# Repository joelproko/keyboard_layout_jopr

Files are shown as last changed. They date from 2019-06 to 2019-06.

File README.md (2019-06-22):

# keyboard_layout_jopr
This is my first attempt at a custom keyboard. It's inspired, among others, by https://github.com/itractus/KeyBored  
The firmware is located at https://github.com/joelproko/qmk_firmware/tree/jopr

This is a layout of what the microcontroller will probably send for which key:  

"default":  
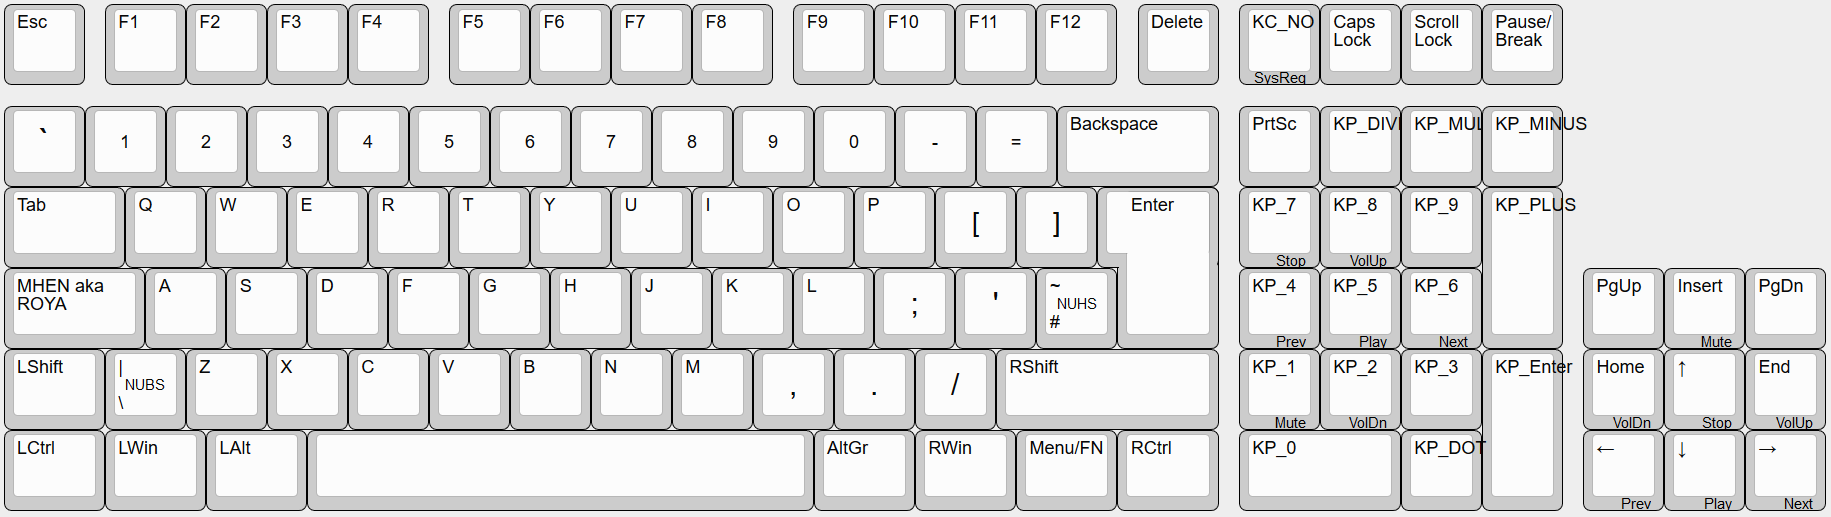
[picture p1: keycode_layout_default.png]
  
[Keyboard Layout Editor link](http://www.keyboard-layout-editor.com/#/gists/82594aeadc8321c39f5dd5e3733b16e5)

"modded-white": (based on https://github.com/mw8/white_keyboard_layout)  
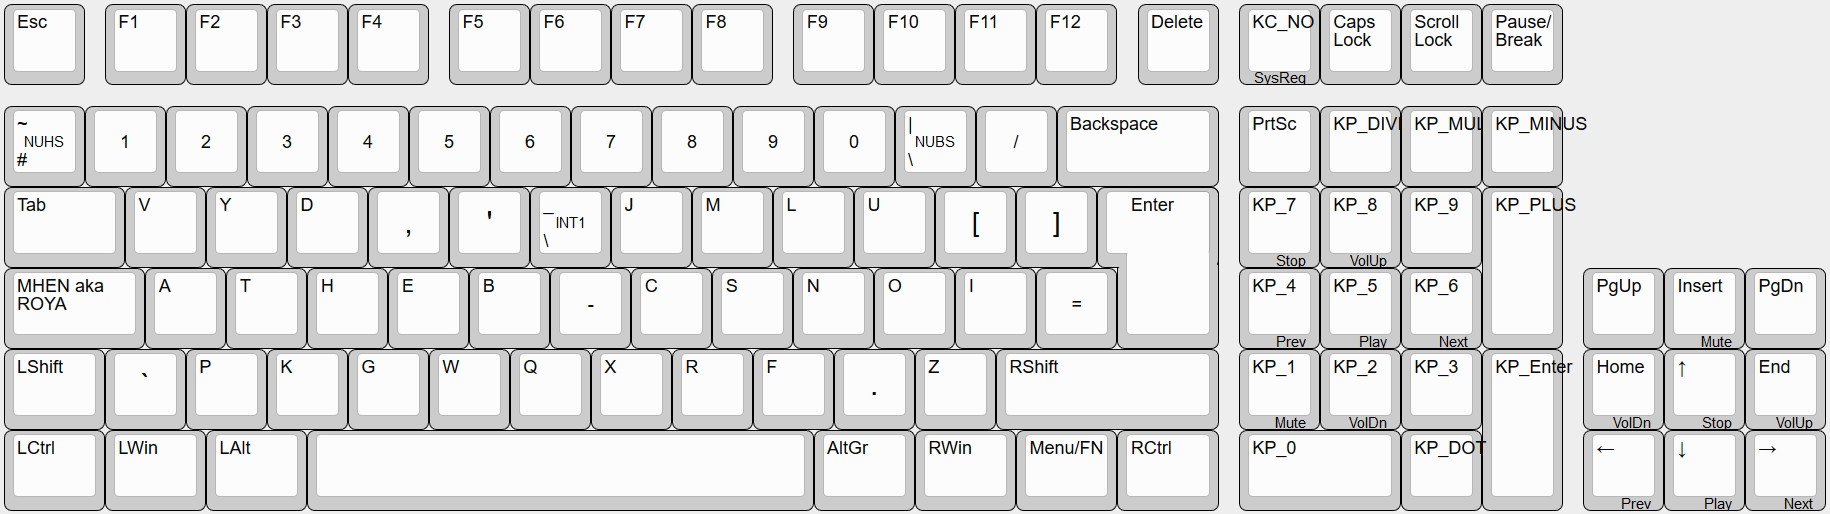
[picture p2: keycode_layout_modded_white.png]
  
[Keyboard Layout Editor link](http://www.keyboard-layout-editor.com/#/gists/e355f587c1d4540c1ec2808fc14671c6)

This a keycap design for the latter:  
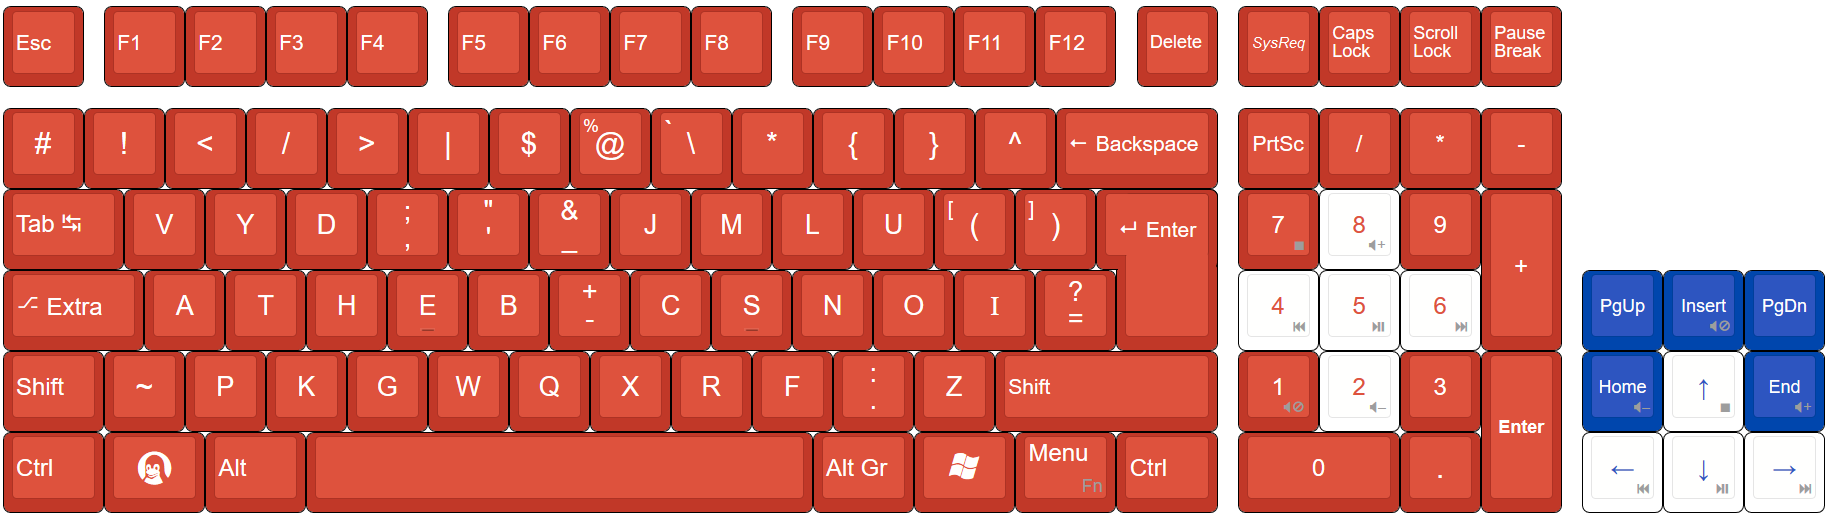
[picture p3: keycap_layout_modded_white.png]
  
[Keyboard Layout Editor link](http://www.keyboard-layout-editor.com/#/gists/73444aee1e5caa922be72c5b2b2db0ba)

There's a PDF of the schematic
here
and a PDF of the PCB
here (and [a version with separate pages for each layer](https://github.com/joelproko/keyboard_layout_jopr/raw/master/keyboard_layout_jopr.kicad_pcb.page_per_layer.pdf))

2019-06-22:  
So far, the PCB and the keycaps have arrived. I made a low quality photo on my phone.  
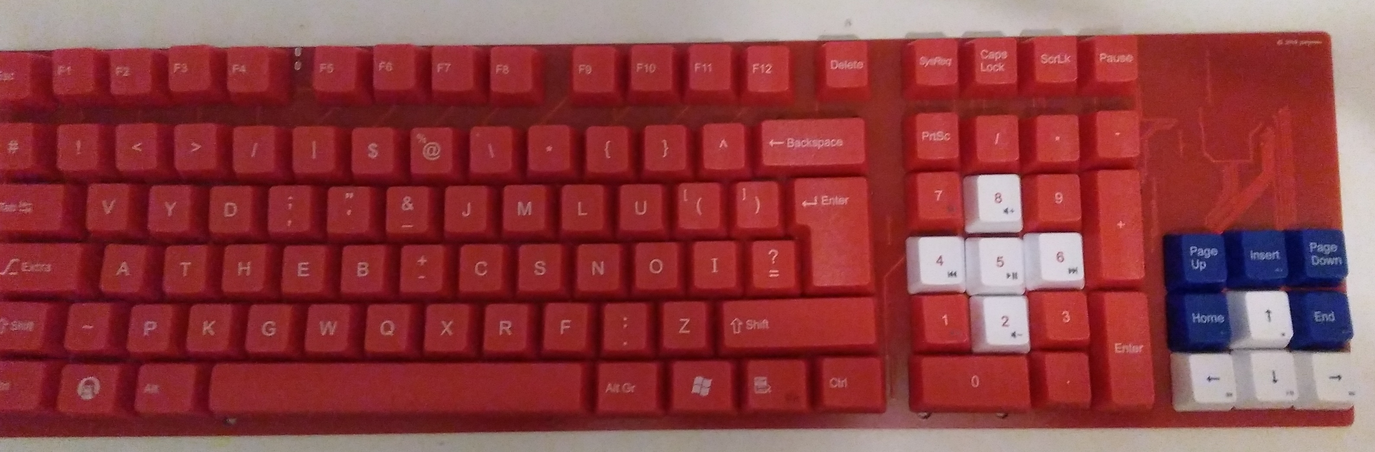
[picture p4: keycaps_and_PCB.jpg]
bad photograph of keycaps on top of PCB


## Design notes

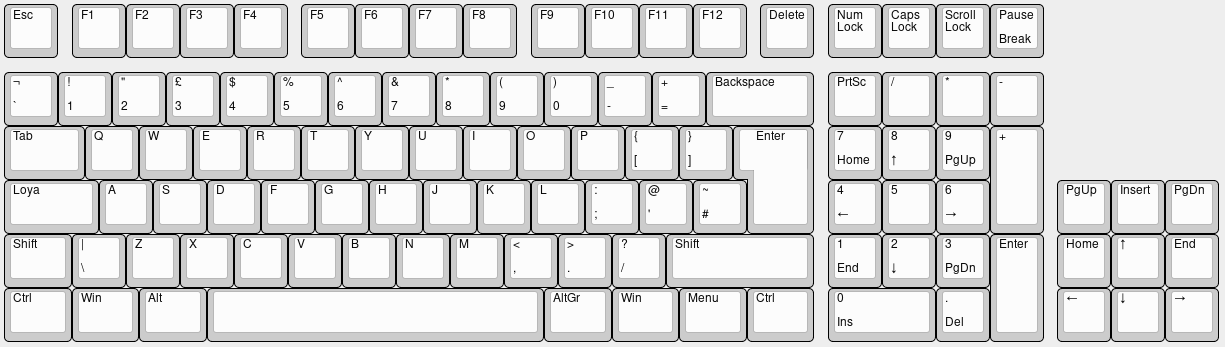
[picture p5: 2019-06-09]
keycode_layout.png

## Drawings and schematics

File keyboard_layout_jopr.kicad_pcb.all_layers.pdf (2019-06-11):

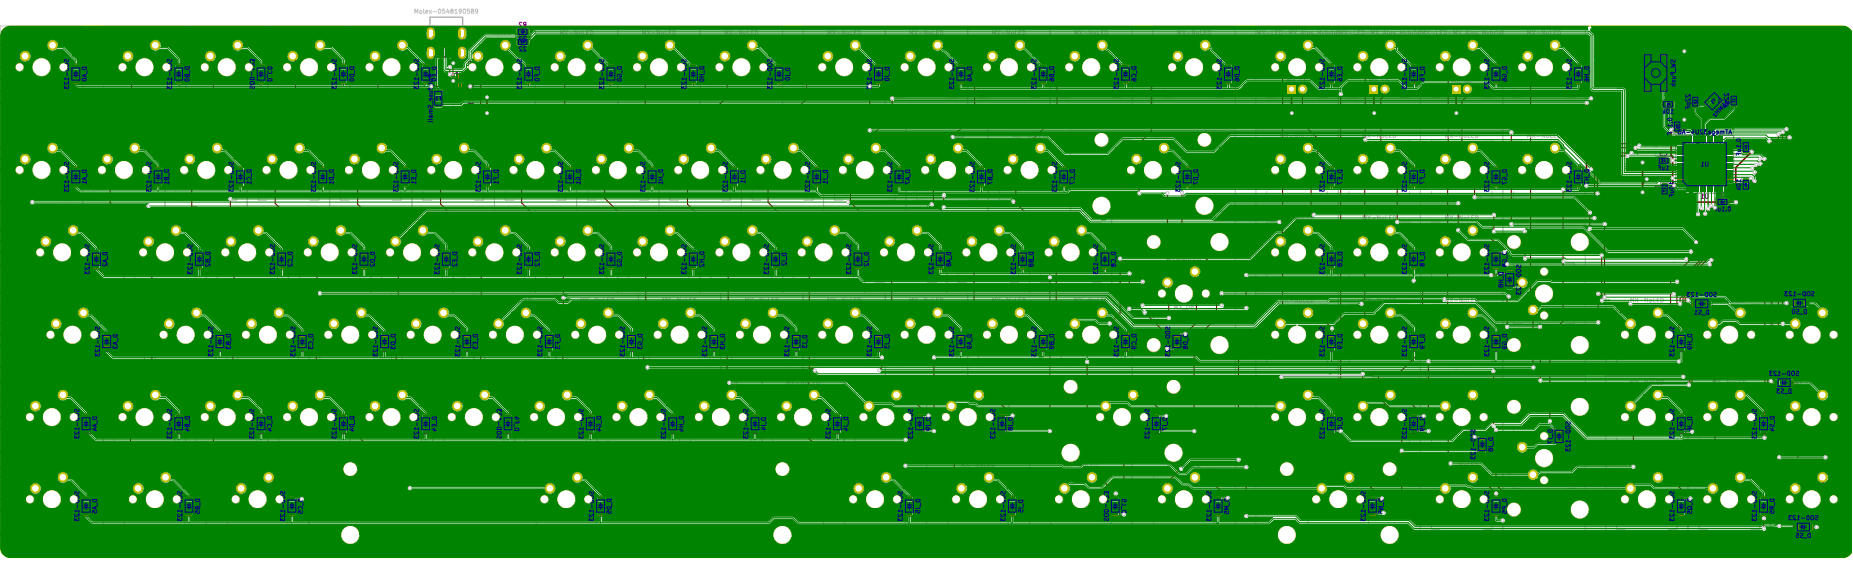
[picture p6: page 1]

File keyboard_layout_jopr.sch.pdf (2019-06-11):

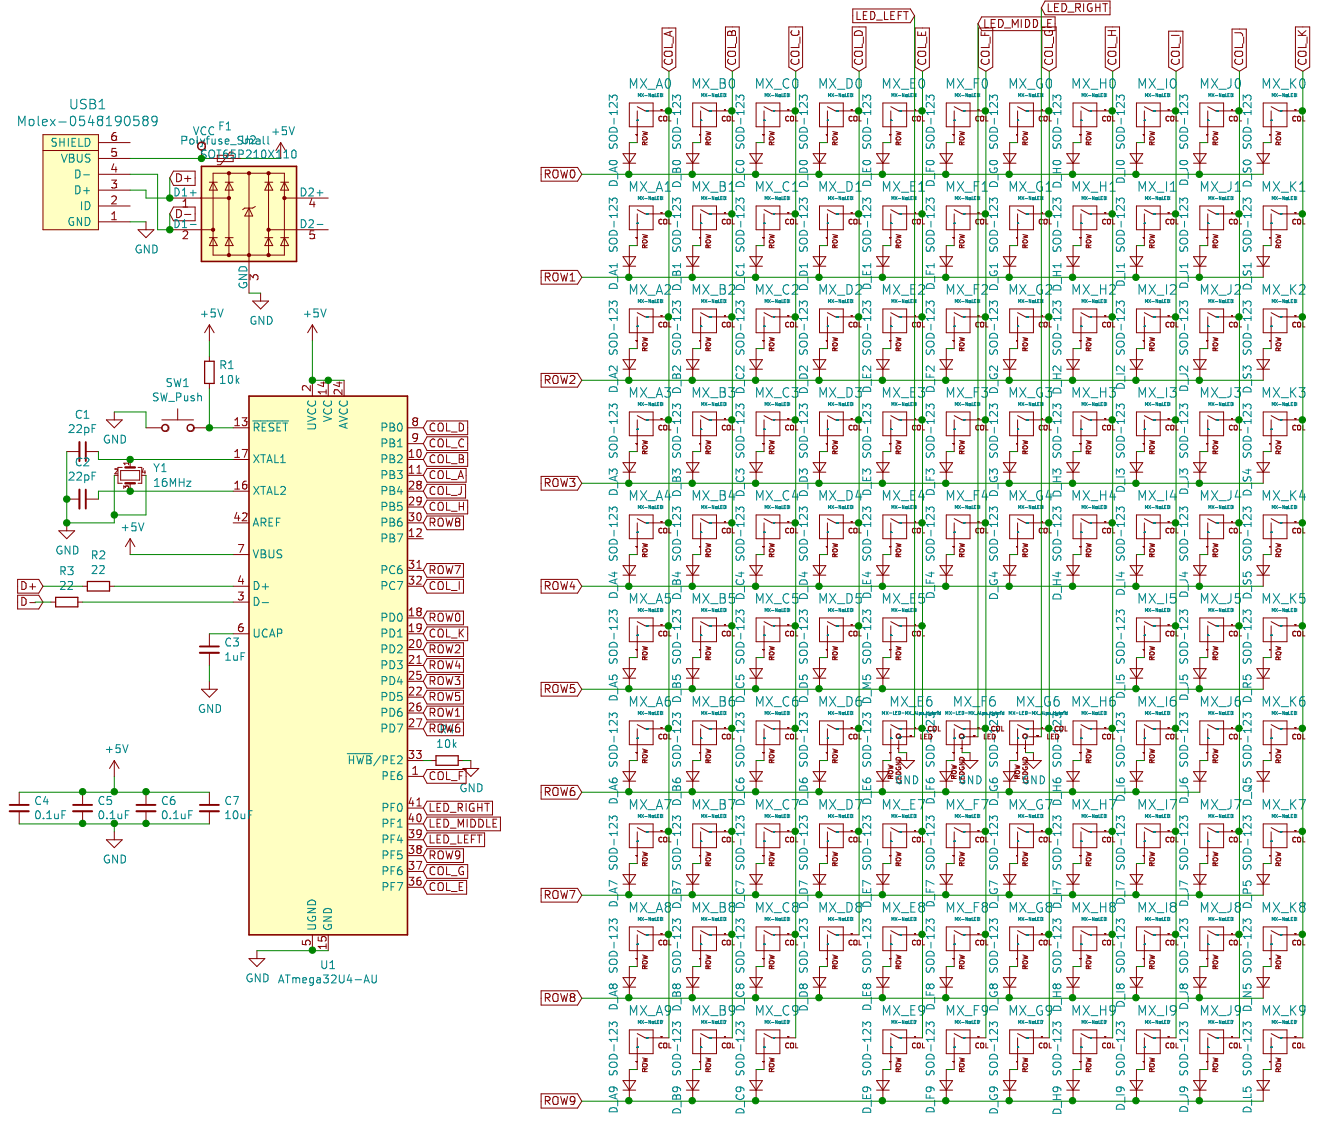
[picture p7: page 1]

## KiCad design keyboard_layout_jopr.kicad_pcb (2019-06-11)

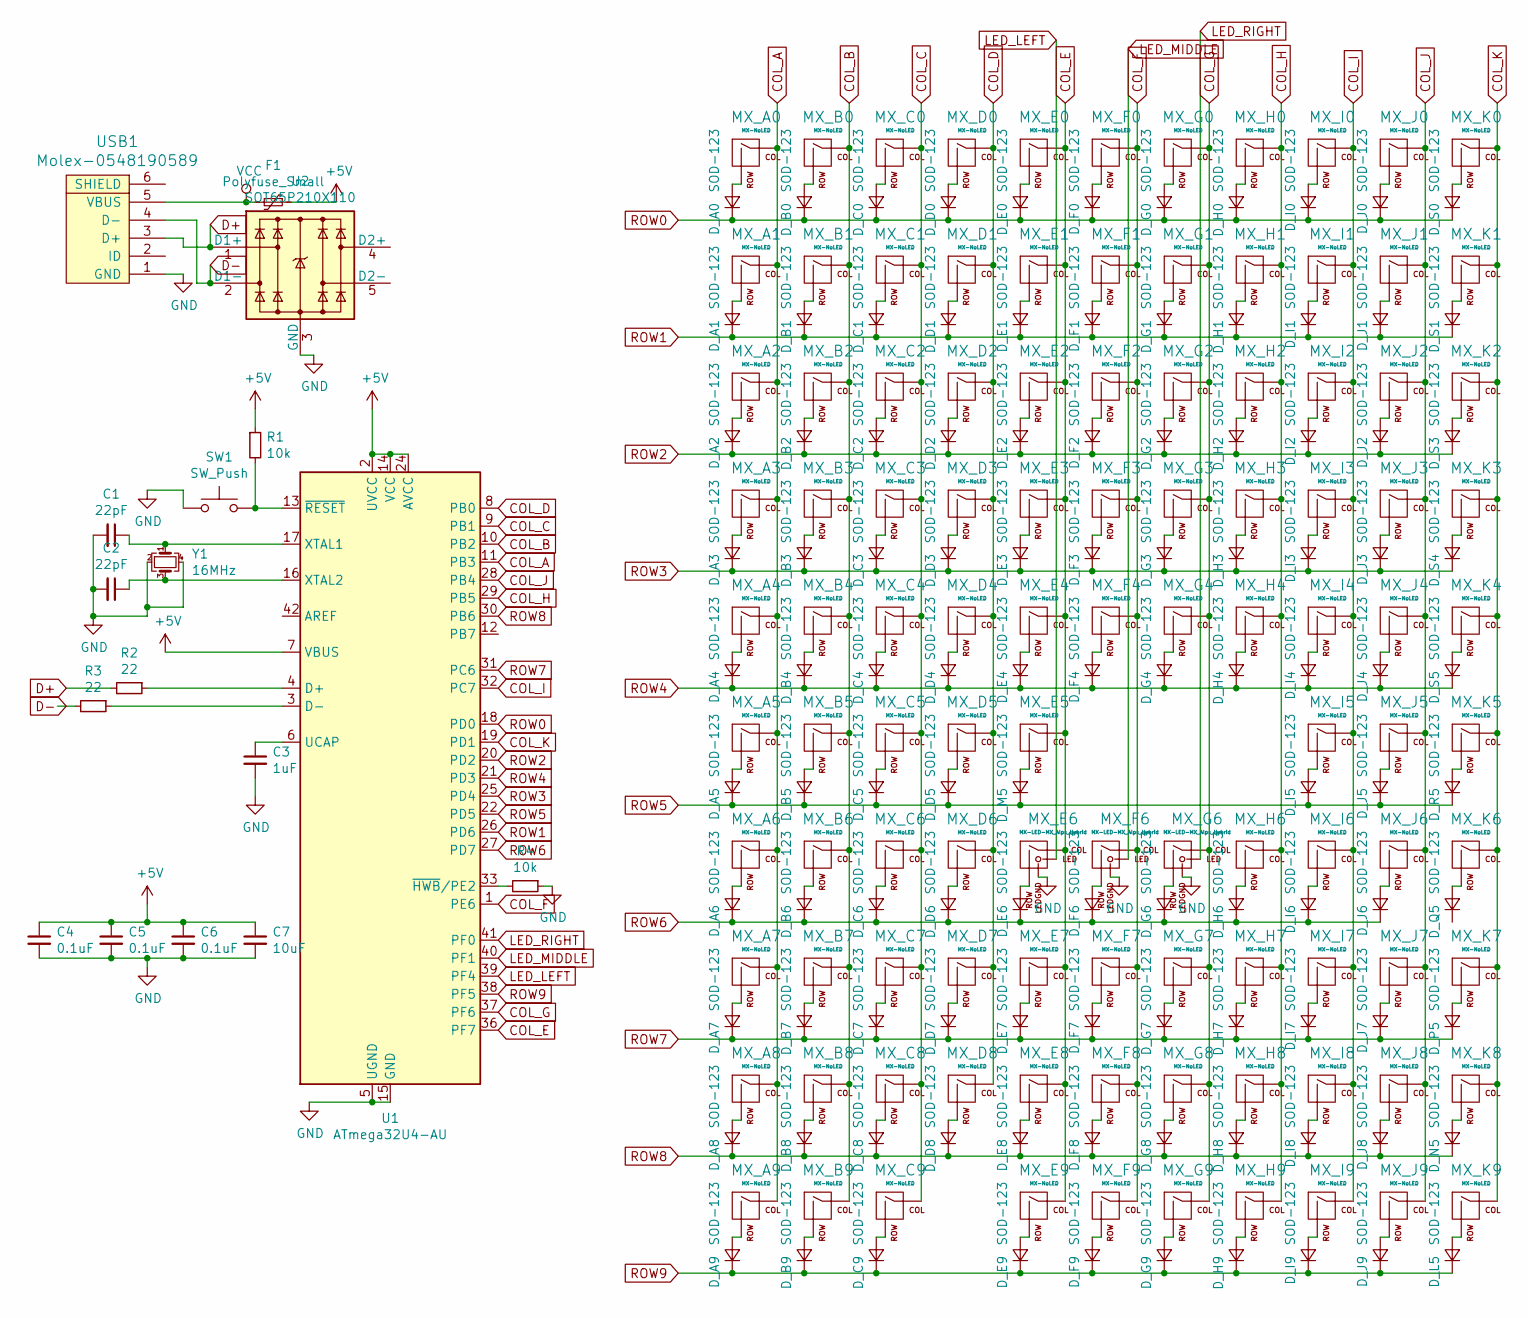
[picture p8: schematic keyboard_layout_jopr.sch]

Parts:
C1, C2: 22pF; C_0805_2012Metric
C3: 1uF; C_0805_2012Metric
C4, C5, C6: 0.1uF; C_0805_2012Metric
C7: 10uF; C_0805_2012Metric
D_A0, D_A1, D_A2, D_A3, D_A4, D_A5, D_A6, D_A7, D_A8, D_A9: SOD-123; D_SOD-123
D_B0, D_B1, D_B2, D_B3, D_B4, D_B5, D_B6, D_B7, D_B8, D_B9: SOD-123; D_SOD-123
D_C0, D_C1, D_C2, D_C3, D_C4, D_C5, D_C6, D_C7, D_C8, D_C9: SOD-123; D_SOD-123
D_D0, D_D1, D_D2, D_D3, D_D4, D_D5, D_D6, D_D7, D_D8: SOD-123; D_SOD-123
D_E0, D_E1, D_E2, D_E3, D_E4, D_E6, D_E7, D_E8, D_E9: SOD-123; D_SOD-123
D_F0, D_F1, D_F2, D_F3, D_F4, D_F6, D_F7, D_F8, D_F9: SOD-123; D_SOD-123
D_G0, D_G1, D_G2, D_G3, D_G4, D_G6, D_G7, D_G8, D_G9: SOD-123; D_SOD-123
D_H0, D_H1, D_H2, D_H3, D_H4, D_H6, D_H7, D_H8, D_H9: SOD-123; D_SOD-123
D_I0, D_I1, D_I2, D_I3, D_I4, D_I5, D_I6, D_I7, D_I8, D_I9: SOD-123; D_SOD-123
D_J0, D_J1, D_J2, D_J3, D_J4, D_J5, D_J6, D_J7, D_J8, D_J9: SOD-123; D_SOD-123
D_L5: SOD-123; D_SOD-123
D_M5: SOD-123; D_SOD-123
D_N5: SOD-123; D_SOD-123
D_P5: SOD-123; D_SOD-123
D_Q5: SOD-123; D_SOD-123
D_R5: SOD-123; D_SOD-123
D_S0, D_S1, D_S3, D_S4, D_S5: SOD-123; D_SOD-123
F1: Polyfuse_Small; Fuse_1206_3216Metric
MX_A0, MX_A1, MX_A6, MX_A7, MX_A8, MX_A9: MX-NoLED; MXOnly-1U-NoLED
MX_A2: MX-NoLED; MXOnly-1.5U-NoLED
MX_A3: MX-NoLED; MXOnly-1.75U-NoLED
MX_A4, MX_A5: MX-NoLED; MXOnly-1.25U-NoLED
MX_B0, MX_B1, MX_B2, MX_B3, MX_B4, MX_B6, MX_B7, MX_B8, MX_B9: MX-NoLED; MXOnly-1U-NoLED
MX_B5: MX-NoLED; MXOnly-1.25U-NoLED
MX_C0, MX_C1, MX_C2, MX_C3, MX_C4, MX_C6, MX_C7, MX_C8, MX_C9: MX-NoLED; MXOnly-1U-NoLED
MX_C5: MX-NoLED; MXOnly-1.25U-NoLED
MX_D0, MX_D1, MX_D2, MX_D3, MX_D4, MX_D6: MX-NoLED; MXOnly-1U-NoLED
MX_D5: MX-NoLED; MXOnly-6.25U-NoLED
MX_D7: MX-NoLED; MXOnly-2U-NoLED
MX_D8: MX-NoLED; MXOnly-ISO-NoLED
MX_E0, MX_E1, MX_E2, MX_E3, MX_E4, MX_E7, MX_E8, MX_E9: MX-NoLED; MXOnly-1U-NoLED
MX_E5: MX-NoLED; MXOnly-1.25U-NoLED
MX_E6: MX-LED-MX_Alps_Hybrid; MXOnly-1U-FLIPPED
MX_F0, MX_F1, MX_F2, MX_F3, MX_F4, MX_F7, MX_F8, MX_F9: MX-NoLED; MXOnly-1U-NoLED
MX_F6: MX-LED-MX_Alps_Hybrid; MXOnly-1U-FLIPPED
MX_G0, MX_G1, MX_G2, MX_G3, MX_G4, MX_G7, MX_G8, MX_G9: MX-NoLED; MXOnly-1U-NoLED
MX_G6: MX-LED-MX_Alps_Hybrid; MXOnly-1U-FLIPPED
MX_H0, MX_H1, MX_H2, MX_H3, MX_H4, MX_H6, MX_H7, MX_H9: MX-NoLED; MXOnly-1U-NoLED
MX_H8: MX-NoLED; MXOnly-2U-NoLED
MX_I0, MX_I1, MX_I2, MX_I3, MX_I4, MX_I6, MX_I8, MX_I9: MX-NoLED; MXOnly-1U-NoLED
MX_I5: MX-NoLED; MXOnly-1.25U-NoLED
MX_I7: MX-NoLED; MXOnly-2.75U-NoLED
MX_J0, MX_J1, MX_J2, MX_J3, MX_J4, MX_J6, MX_J8, MX_J9: MX-NoLED; MXOnly-1U-NoLED
MX_J5: MX-NoLED; MXOnly-1.25U-NoLED
MX_J7: MX-NoLED; MXOnly-2U-NoLED
MX_K0, MX_K1, MX_K2, MX_K3, MX_K4, MX_K5, MX_K6, MX_K7: MX-NoLED; MXOnly-1U-NoLED
MX_K8: MX-NoLED; MXOnly-2U-NoLED
MX_K9: MX-NoLED; MXOnly-1.25U-NoLED
R1, R4: 10k; R_0805_2012Metric
R2, R3: 22; R_0805_2012Metric
SW1: SW_Push; SKQG-1155865
U1: ATmega32U4-AU; TQFP-44_10x10mm_P0.8mm
U2: SOT65P210X110; SOT65P210X110-6N
USB1: Molex-0548190589
Y1: 16MHz; Crystal_SMD_3225-4Pin_3.2x2.5mm

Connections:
+5V: C4.1, C5.1, C6.1, C7.1, F1.1, R1.1, U1.2 (UVCC), U1.7 (VBUS), U1.14 (VCC), U1.24 (AVCC), U1.34 (VCC), U1.44 (AVCC)
COL_A: MX_A0.1 (COL), MX_A1.1 (COL), MX_A2.1 (COL), MX_A3.1 (COL), MX_A4.1 (COL), MX_A5.1 (COL), MX_A6.1 (COL), MX_A7.1 (COL), MX_A8.1 (COL), MX_A9.1 (COL), U1.11 (PB3)
COL_B: MX_B0.1 (COL), MX_B1.1 (COL), MX_B2.1 (COL), MX_B3.1 (COL), MX_B4.1 (COL), MX_B5.1 (COL), MX_B6.1 (COL), MX_B7.1 (COL), MX_B8.1 (COL), MX_B9.1 (COL), U1.10 (PB2)
COL_C: MX_C0.1 (COL), MX_C1.1 (COL), MX_C2.1 (COL), MX_C3.1 (COL), MX_C4.1 (COL), MX_C5.1 (COL), MX_C6.1 (COL), MX_C7.1 (COL), MX_C8.1 (COL), MX_C9.1 (COL), U1.9 (PB1)
COL_D: MX_D0.1 (COL), MX_D1.1 (COL), MX_D2.1 (COL), MX_D3.1 (COL), MX_D4.1 (COL), MX_D5.1 (COL), MX_D6.1 (COL), MX_D7.1 (COL), MX_D8.1 (COL), U1.8 (PB0)
COL_E: MX_E0.1 (COL), MX_E1.1 (COL), MX_E2.1 (COL), MX_E3.1 (COL), MX_E4.1 (COL), MX_E5.1 (COL), MX_E6.1 (COL), MX_E7.1 (COL), MX_E8.1 (COL), MX_E9.1 (COL), U1.36 (PF7)
COL_F: MX_F0.1 (COL), MX_F1.1 (COL), MX_F2.1 (COL), MX_F3.1 (COL), MX_F4.1 (COL), MX_F6.1 (COL), MX_F7.1 (COL), MX_F8.1 (COL), MX_F9.1 (COL), U1.1 (PE6)
COL_G: MX_G0.1 (COL), MX_G1.1 (COL), MX_G2.1 (COL), MX_G3.1 (COL), MX_G4.1 (COL), MX_G6.1 (COL), MX_G7.1 (COL), MX_G8.1 (COL), MX_G9.1 (COL), U1.37 (PF6)
COL_H: MX_H0.1 (COL), MX_H1.1 (COL), MX_H2.1 (COL), MX_H3.1 (COL), MX_H4.1 (COL), MX_H6.1 (COL), MX_H7.1 (COL), MX_H8.1 (COL), MX_H9.1 (COL), U1.29 (PB5)
COL_I: MX_I0.1 (COL), MX_I1.1 (COL), MX_I2.1 (COL), MX_I3.1 (COL), MX_I4.1 (COL), MX_I5.1 (COL), MX_I6.1 (COL), MX_I7.1 (COL), MX_I8.1 (COL), MX_I9.1 (COL), U1.32 (PC7)
COL_J: MX_J0.1 (COL), MX_J1.1 (COL), MX_J2.1 (COL), MX_J3.1 (COL), MX_J4.1 (COL), MX_J5.1 (COL), MX_J6.1 (COL), MX_J7.1 (COL), MX_J8.1 (COL), MX_J9.1 (COL), U1.28 (PB4)
COL_K: MX_K0.1 (COL), MX_K1.1 (COL), MX_K2.1 (COL), MX_K3.1 (COL), MX_K4.1 (COL), MX_K5.1 (COL), MX_K6.1 (COL), MX_K7.1 (COL), MX_K8.1 (COL), MX_K9.1 (COL), U1.19 (PD1)
D+: R2.2, U2.1 (D1+), USB1.3 (D+)
D-: R3.2, U2.2 (D1-), USB1.4 (D-)
GND: C1.2, C2.2, C3.2, C4.2, C5.2, C6.2, C7.2, MX_E6.4 (LEDGND), MX_F6.4 (LEDGND), MX_G6.4 (LEDGND), R4.1, SW1.1, U1.5 (UGND), U1.15 (GND), U1.23 (GND), U1.35 (GND), U1.43 (GND), U2.3 (GND), U2.8 (GND), USB1.1 (GND), Y1.2, Y1.4
LED_LEFT: MX_E6.3 (LED), U1.39 (PF4)
LED_MIDDLE: MX_F6.3 (LED), U1.40 (PF1)
LED_RIGHT: MX_G6.3 (LED), U1.41 (PF0)
unnamed: C1.1, U1.17 (XTAL1), Y1.1
unnamed: C2.1, U1.16 (XTAL2), Y1.3
unnamed: C3.1, U1.6 (UCAP)
unnamed: D_A0.2 (A), MX_A0.2 (ROW)
unnamed: D_A1.2 (A), MX_A1.2 (ROW)
unnamed: D_A2.2 (A), MX_A2.2 (ROW)
unnamed: D_A3.2 (A), MX_A3.2 (ROW)
unnamed: D_A4.2 (A), MX_A4.2 (ROW)
unnamed: D_A5.2 (A), MX_A5.2 (ROW)
unnamed: D_A6.2 (A), MX_A6.2 (ROW)
unnamed: D_A7.2 (A), MX_A7.2 (ROW)
unnamed: D_A8.2 (A), MX_A8.2 (ROW)
unnamed: D_A9.2 (A), MX_A9.2 (ROW)
unnamed: D_B0.2 (A), MX_B0.2 (ROW)
unnamed: D_B1.2 (A), MX_B1.2 (ROW)
unnamed: D_B2.2 (A), MX_B2.2 (ROW)
unnamed: D_B3.2 (A), MX_B3.2 (ROW)
unnamed: D_B4.2 (A), MX_B4.2 (ROW)
unnamed: D_B5.2 (A), MX_B5.2 (ROW)
unnamed: D_B6.2 (A), MX_B6.2 (ROW)
unnamed: D_B7.2 (A), MX_B7.2 (ROW)
unnamed: D_B8.2 (A), MX_B8.2 (ROW)
unnamed: D_B9.2 (A), MX_B9.2 (ROW)
unnamed: D_C0.2 (A), MX_C0.2 (ROW)
unnamed: D_C1.2 (A), MX_C1.2 (ROW)
unnamed: D_C2.2 (A), MX_C2.2 (ROW)
unnamed: D_C3.2 (A), MX_C3.2 (ROW)
unnamed: D_C4.2 (A), MX_C4.2 (ROW)
unnamed: D_C5.2 (A), MX_C5.2 (ROW)
unnamed: D_C6.2 (A), MX_C6.2 (ROW)
unnamed: D_C7.2 (A), MX_C7.2 (ROW)
unnamed: D_C8.2 (A), MX_C8.2 (ROW)
unnamed: D_C9.2 (A), MX_C9.2 (ROW)
unnamed: D_D0.2 (A), MX_D0.2 (ROW)
unnamed: D_D1.2 (A), MX_D1.2 (ROW)
unnamed: D_D2.2 (A), MX_D2.2 (ROW)
unnamed: D_D3.2 (A), MX_D3.2 (ROW)
unnamed: D_D4.2 (A), MX_D4.2 (ROW)
unnamed: D_D5.2 (A), MX_D5.2 (ROW)
unnamed: D_D6.2 (A), MX_D6.2 (ROW)
unnamed: D_D7.2 (A), MX_D7.2 (ROW)
unnamed: D_D8.2 (A), MX_D8.2 (ROW)
unnamed: D_E0.2 (A), MX_E0.2 (ROW)
unnamed: D_E1.2 (A), MX_E1.2 (ROW)
unnamed: D_E2.2 (A), MX_E2.2 (ROW)
unnamed: D_E3.2 (A), MX_E3.2 (ROW)
unnamed: D_E4.2 (A), MX_E4.2 (ROW)
unnamed: D_E6.2 (A), MX_E6.2 (ROW)
unnamed: D_E7.2 (A), MX_E7.2 (ROW)
unnamed: D_E8.2 (A), MX_E8.2 (ROW)
unnamed: D_E9.2 (A), MX_E9.2 (ROW)
unnamed: D_F0.2 (A), MX_F0.2 (ROW)
unnamed: D_F1.2 (A), MX_F1.2 (ROW)
unnamed: D_F2.2 (A), MX_F2.2 (ROW)
unnamed: D_F3.2 (A), MX_F3.2 (ROW)
unnamed: D_F4.2 (A), MX_F4.2 (ROW)
unnamed: D_F6.2 (A), MX_F6.2 (ROW)
unnamed: D_F7.2 (A), MX_F7.2 (ROW)
unnamed: D_F8.2 (A), MX_F8.2 (ROW)
unnamed: D_F9.2 (A), MX_F9.2 (ROW)
unnamed: D_G0.2 (A), MX_G0.2 (ROW)
unnamed: D_G1.2 (A), MX_G1.2 (ROW)
unnamed: D_G2.2 (A), MX_G2.2 (ROW)
unnamed: D_G3.2 (A), MX_G3.2 (ROW)
unnamed: D_G4.2 (A), MX_G4.2 (ROW)
unnamed: D_G6.2 (A), MX_G6.2 (ROW)
unnamed: D_G7.2 (A), MX_G7.2 (ROW)
unnamed: D_G8.2 (A), MX_G8.2 (ROW)
unnamed: D_G9.2 (A), MX_G9.2 (ROW)
unnamed: D_H0.2 (A), MX_H0.2 (ROW)
unnamed: D_H1.2 (A), MX_H1.2 (ROW)
unnamed: D_H2.2 (A), MX_H2.2 (ROW)
unnamed: D_H3.2 (A), MX_H3.2 (ROW)
unnamed: D_H4.2 (A), MX_H4.2 (ROW)
unnamed: D_H6.2 (A), MX_H6.2 (ROW)
unnamed: D_H7.2 (A), MX_H7.2 (ROW)
unnamed: D_H8.2 (A), MX_H8.2 (ROW)
unnamed: D_H9.2 (A), MX_H9.2 (ROW)
unnamed: D_I0.2 (A), MX_I0.2 (ROW)
unnamed: D_I1.2 (A), MX_I1.2 (ROW)
unnamed: D_I2.2 (A), MX_I2.2 (ROW)
unnamed: D_I3.2 (A), MX_I3.2 (ROW)
unnamed: D_I4.2 (A), MX_I4.2 (ROW)
unnamed: D_I5.2 (A), MX_I5.2 (ROW)
unnamed: D_I6.2 (A), MX_I6.2 (ROW)
unnamed: D_I7.2 (A), MX_I7.2 (ROW)
unnamed: D_I8.2 (A), MX_I8.2 (ROW)
unnamed: D_I9.2 (A), MX_I9.2 (ROW)
unnamed: D_J0.2 (A), MX_J0.2 (ROW)
unnamed: D_J1.2 (A), MX_J1.2 (ROW)
unnamed: D_J2.2 (A), MX_J2.2 (ROW)
unnamed: D_J3.2 (A), MX_J3.2 (ROW)
unnamed: D_J4.2 (A), MX_J4.2 (ROW)
unnamed: D_J5.2 (A), MX_J5.2 (ROW)
unnamed: D_J6.2 (A), MX_J6.2 (ROW)
unnamed: D_J7.2 (A), MX_J7.2 (ROW)
unnamed: D_J8.2 (A), MX_J8.2 (ROW)
unnamed: D_J9.2 (A), MX_J9.2 (ROW)
unnamed: D_L5.2 (A), MX_K9.2 (ROW)
unnamed: D_M5.2 (A), MX_E5.2 (ROW)
unnamed: D_N5.2 (A), MX_K8.2 (ROW)
unnamed: D_P5.2 (A), MX_K7.2 (ROW)
unnamed: D_Q5.2 (A), MX_K6.2 (ROW)
unnamed: D_R5.2 (A), MX_K5.2 (ROW)
unnamed: D_S0.2 (A), MX_K0.2 (ROW)
unnamed: D_S1.2 (A), MX_K1.2 (ROW)
unnamed: D_S3.2 (A), MX_K2.2 (ROW)
unnamed: D_S4.2 (A), MX_K3.2 (ROW)
unnamed: D_S5.2 (A), MX_K4.2 (ROW)
unnamed: R1.2, SW1.2, U1.13 (~RESET)
unnamed: R2.1, U1.4 (D+)
unnamed: R3.1, U1.3 (D-)
unnamed: R4.2, U1.33 (~HWB~/PE2)
ROW0: D_A0.1 (K), D_B0.1 (K), D_C0.1 (K), D_D0.1 (K), D_E0.1 (K), D_F0.1 (K), D_G0.1 (K), D_H0.1 (K), D_I0.1 (K), D_J0.1 (K), D_S0.1 (K), U1.18 (PD0)
ROW1: D_A1.1 (K), D_B1.1 (K), D_C1.1 (K), D_D1.1 (K), D_E1.1 (K), D_F1.1 (K), D_G1.1 (K), D_H1.1 (K), D_I1.1 (K), D_J1.1 (K), D_S1.1 (K), U1.26 (PD6)
ROW2: D_A2.1 (K), D_B2.1 (K), D_C2.1 (K), D_D2.1 (K), D_E2.1 (K), D_F2.1 (K), D_G2.1 (K), D_H2.1 (K), D_I2.1 (K), D_J2.1 (K), D_S3.1 (K), U1.20 (PD2)
ROW3: D_A3.1 (K), D_B3.1 (K), D_C3.1 (K), D_D3.1 (K), D_E3.1 (K), D_F3.1 (K), D_G3.1 (K), D_H3.1 (K), D_I3.1 (K), D_J3.1 (K), D_S4.1 (K), U1.25 (PD4)
ROW4: D_A4.1 (K), D_B4.1 (K), D_C4.1 (K), D_D4.1 (K), D_E4.1 (K), D_F4.1 (K), D_G4.1 (K), D_H4.1 (K), D_I4.1 (K), D_J4.1 (K), D_S5.1 (K), U1.21 (PD3)
ROW5: D_A5.1 (K), D_B5.1 (K), D_C5.1 (K), D_D5.1 (K), D_I5.1 (K), D_J5.1 (K), D_M5.1 (K), D_R5.1 (K), U1.22 (PD5)
ROW6: D_A6.1 (K), D_B6.1 (K), D_C6.1 (K), D_D6.1 (K), D_E6.1 (K), D_F6.1 (K), D_G6.1 (K), D_H6.1 (K), D_I6.1 (K), D_J6.1 (K), U1.27 (PD7)
ROW7: D_A7.1 (K), D_B7.1 (K), D_C7.1 (K), D_D7.1 (K), D_E7.1 (K), D_F7.1 (K), D_G7.1 (K), D_H7.1 (K), D_I7.1 (K), D_J7.1 (K), D_P5.1 (K), U1.31 (PC6)
ROW8: D_A8.1 (K), D_B8.1 (K), D_C8.1 (K), D_D8.1 (K), D_E8.1 (K), D_F8.1 (K), D_G8.1 (K), D_H8.1 (K), D_I8.1 (K), D_J8.1 (K), D_N5.1 (K), U1.30 (PB6)
ROW9: D_A9.1 (K), D_B9.1 (K), D_C9.1 (K), D_E9.1 (K), D_F9.1 (K), D_G9.1 (K), D_H9.1 (K), D_I9.1 (K), D_J9.1 (K), D_L5.1 (K), U1.38 (PF5)
VCC: F1.2, USB1.5 (VBUS)

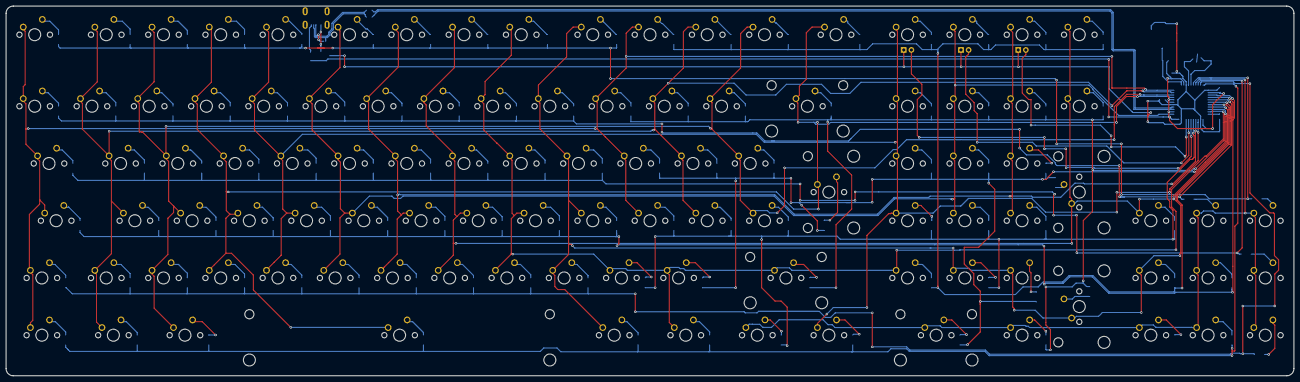
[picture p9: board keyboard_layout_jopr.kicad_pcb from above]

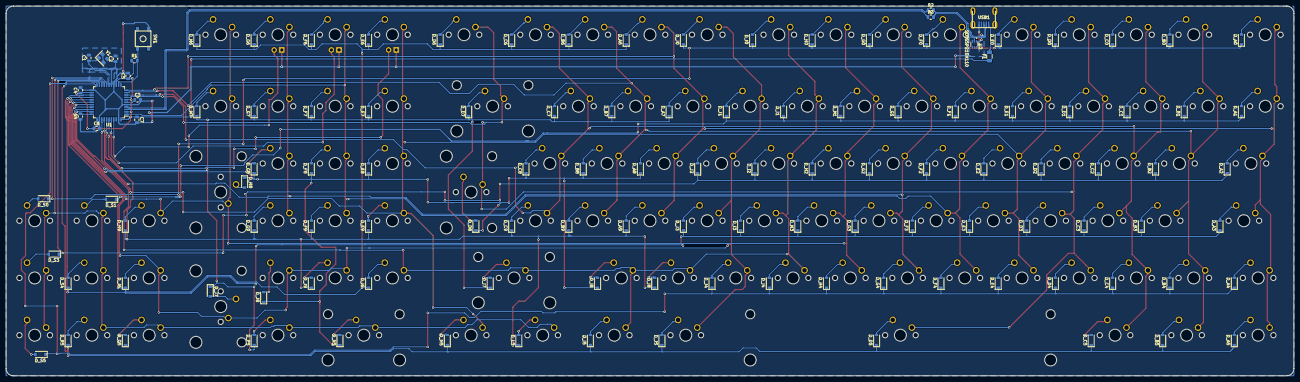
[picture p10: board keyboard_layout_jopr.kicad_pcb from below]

Board: 2 copper layers, 428.6 x 123.0 mm, 229 parts (123 on the bottom side), 142 nets.

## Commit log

2019-06-07 kicad init
    [keyboard_layout_jopr.kicad_pcb, keyboard_layout_jopr.sch]
2019-06-08 maybe done with the kicad part?
2019-06-08 Inter-key tracks and USB Data tracks only
    [keyboard_layout_jopr.kicad_pcb, keyboard_layout_jopr.sch, keyboard_layout_jopr_v01.kicad_pcb]
2019-06-08 maybe better tracks
    [keyboard_layout_jopr.kicad_pcb, keyboard_layout_jopr.sch, keyboard_layout_jopr_v01.kicad_pcb]
2019-06-09 replaced MX_Hybrid with MX_Only footprints
    [keyboard_layout_jopr.kicad_pcb]
2019-06-09 PDF-Versions of current state of schematic and pcb
2019-06-10 added ESD-protection
    [keyboard_layout_jopr.kicad_pcb, keyboard_layout_jopr.sch]
2019-06-11 squared matrix, updated and renamed PDFs
    [keyboard_layout_jopr.kicad_pcb, keyboard_layout_jopr.sch]
2019-06-11 generated Gerber files
    [keyboard_layout_jopr-B_Cu.gbr, keyboard_layout_jopr-B_Mask.gbr, keyboard_layout_jopr-B_SilkS.gbr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]
2019-06-11 moved lower edge down
    [keyboard_layout_jopr-B_Cu.gbr, keyboard_layout_jopr-B_Mask.gbr, keyboard_layout_jopr-B_SilkS.gbr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]
2019-06-11 moved lower PCB edge down
    [keyboard_layout_jopr-B_Cu.gbr, keyboard_layout_jopr-B_Mask.gbr, keyboard_layout_jopr-B_SilkS.gbr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]
2019-06-11 added LEDs for Lock keys
    [keyboard_layout_jopr-B_Cu.gbr, keyboard_layout_jopr-B_Mask.gbr, keyboard_layout_jopr-B_SilkS.gbr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]
2019-06-11 updated Gerber Zip
    [keyboard_layout_jopr-B_Cu.gbr, keyboard_layout_jopr-B_Mask.gbr, keyboard_layout_jopr-B_SilkS.gbr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]
